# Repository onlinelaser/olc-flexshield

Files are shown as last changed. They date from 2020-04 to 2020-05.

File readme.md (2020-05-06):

## FLEXSHIELD v1

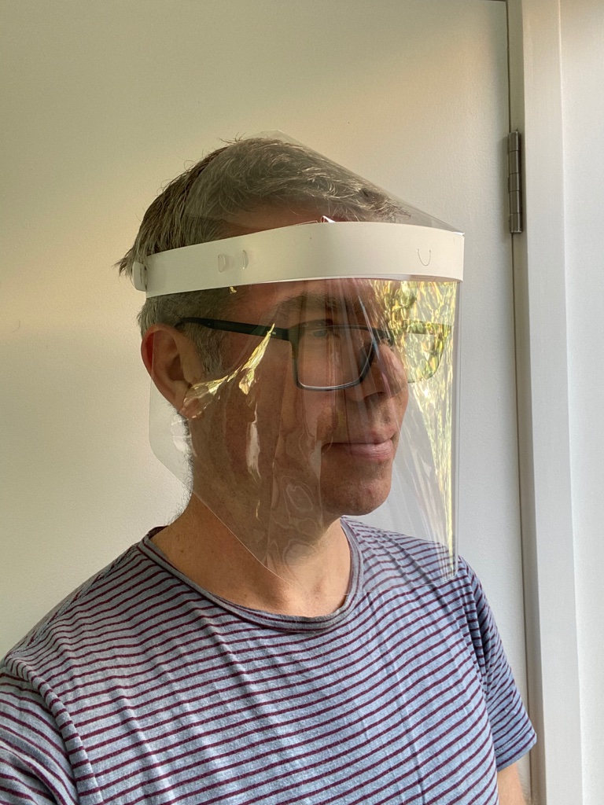
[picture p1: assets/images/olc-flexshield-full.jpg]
Full face variant


This is a disposable and/or reusable face shield design, it's currently in the early stages of review by our local hospitals and this iteration addresses a couple of issues from our previous design.

1) Integrated shield cover now extends coverage over the front of the top of the head.

2) Fully sanitisable materials in Isopropyl alcohol - specifically no foam or adhesive parts are required that would be degraded by washing/sanitising

3) Split the design into a Full Face version that wraps over the top of the head for more protection and a standard version that simply wraps around the face and can be produced in larger quantities.

**Note that this is not an approved medical or protective device and has not been tested or certified as fit for any restricted use.**

## Source attribution
[Online Laser Cutting](https://onlinelasercutting.com.au)

## Open Source License
Copyright Online Laser Cutting Pty Ltd 2020.

This source describes Open Hardware and is licensed under the CERN-OHL-P
v2

You may redistribute and modify this documentation and make products
using it under the terms of the CERN-OHL-P v2 (https:/cern.ch/cern-ohl).

This documentation is distributed WITHOUT ANY EXPRESS OR IMPLIED
WARRANTY, INCLUDING OF MERCHANTABILITY, SATISFACTORY QUALITY
AND FITNESS FOR A PARTICULAR PURPOSE. Please see the CERN-OHL-P v2
for applicable conditions

## Sterilising protocol
Designed to withstand sterilising in 99%+ Alochol based on:
See: https://www.calpaclab.com/polypropylene-chemical-compatibility-chart/  
See: https://www.usplastic.com/knowledgebase/article.aspx?contentkey=569

Initial testing on a 50 deg Centigrade VHP cycle indicated shield was still 
fully functional after 5 cycles - more testing is required however.

## Lifespan:
Single or Multiple use.  
Should happily withstand multiple 99% Alcohol wash cycles and appears fine with low temperature VHP sterilisation.

## Design notes:
Strap size should fit 97%+ of the population

## BOM
* 1 x 0.1mm Polyester OR 0.5mm PETG faceplate
* 1 x 0.8mm Polypropylene head band
* 1 x 0.8mm Polypropylene brow strap

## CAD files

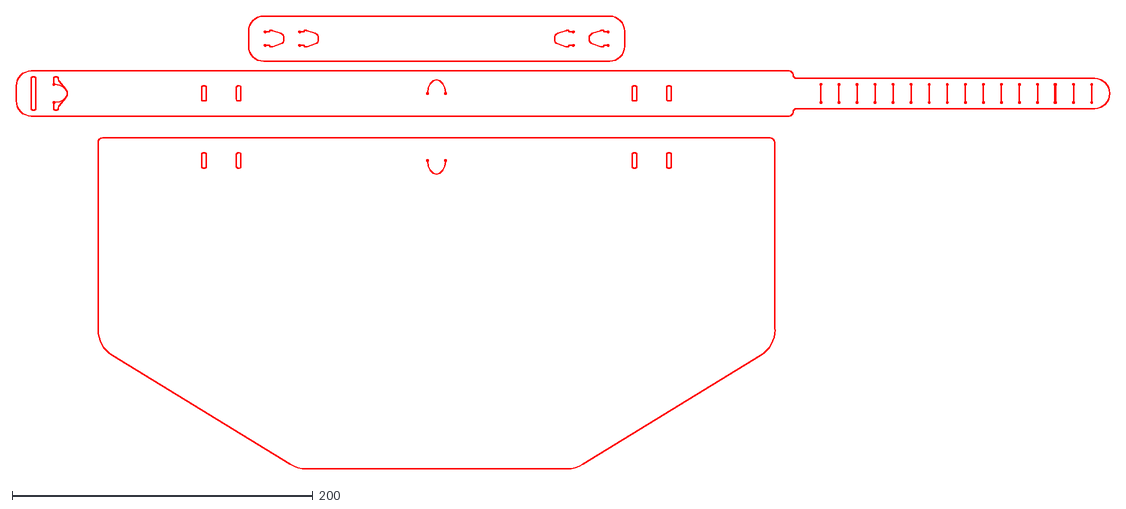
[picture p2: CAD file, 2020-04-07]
Flexible Frame Standard.dxf
726.9 x 301.0

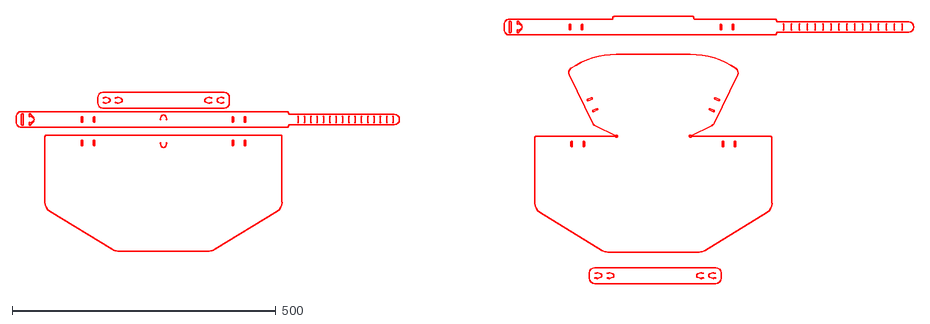
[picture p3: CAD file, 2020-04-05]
Flexible Frame.dxf
1702.5 x 506.5

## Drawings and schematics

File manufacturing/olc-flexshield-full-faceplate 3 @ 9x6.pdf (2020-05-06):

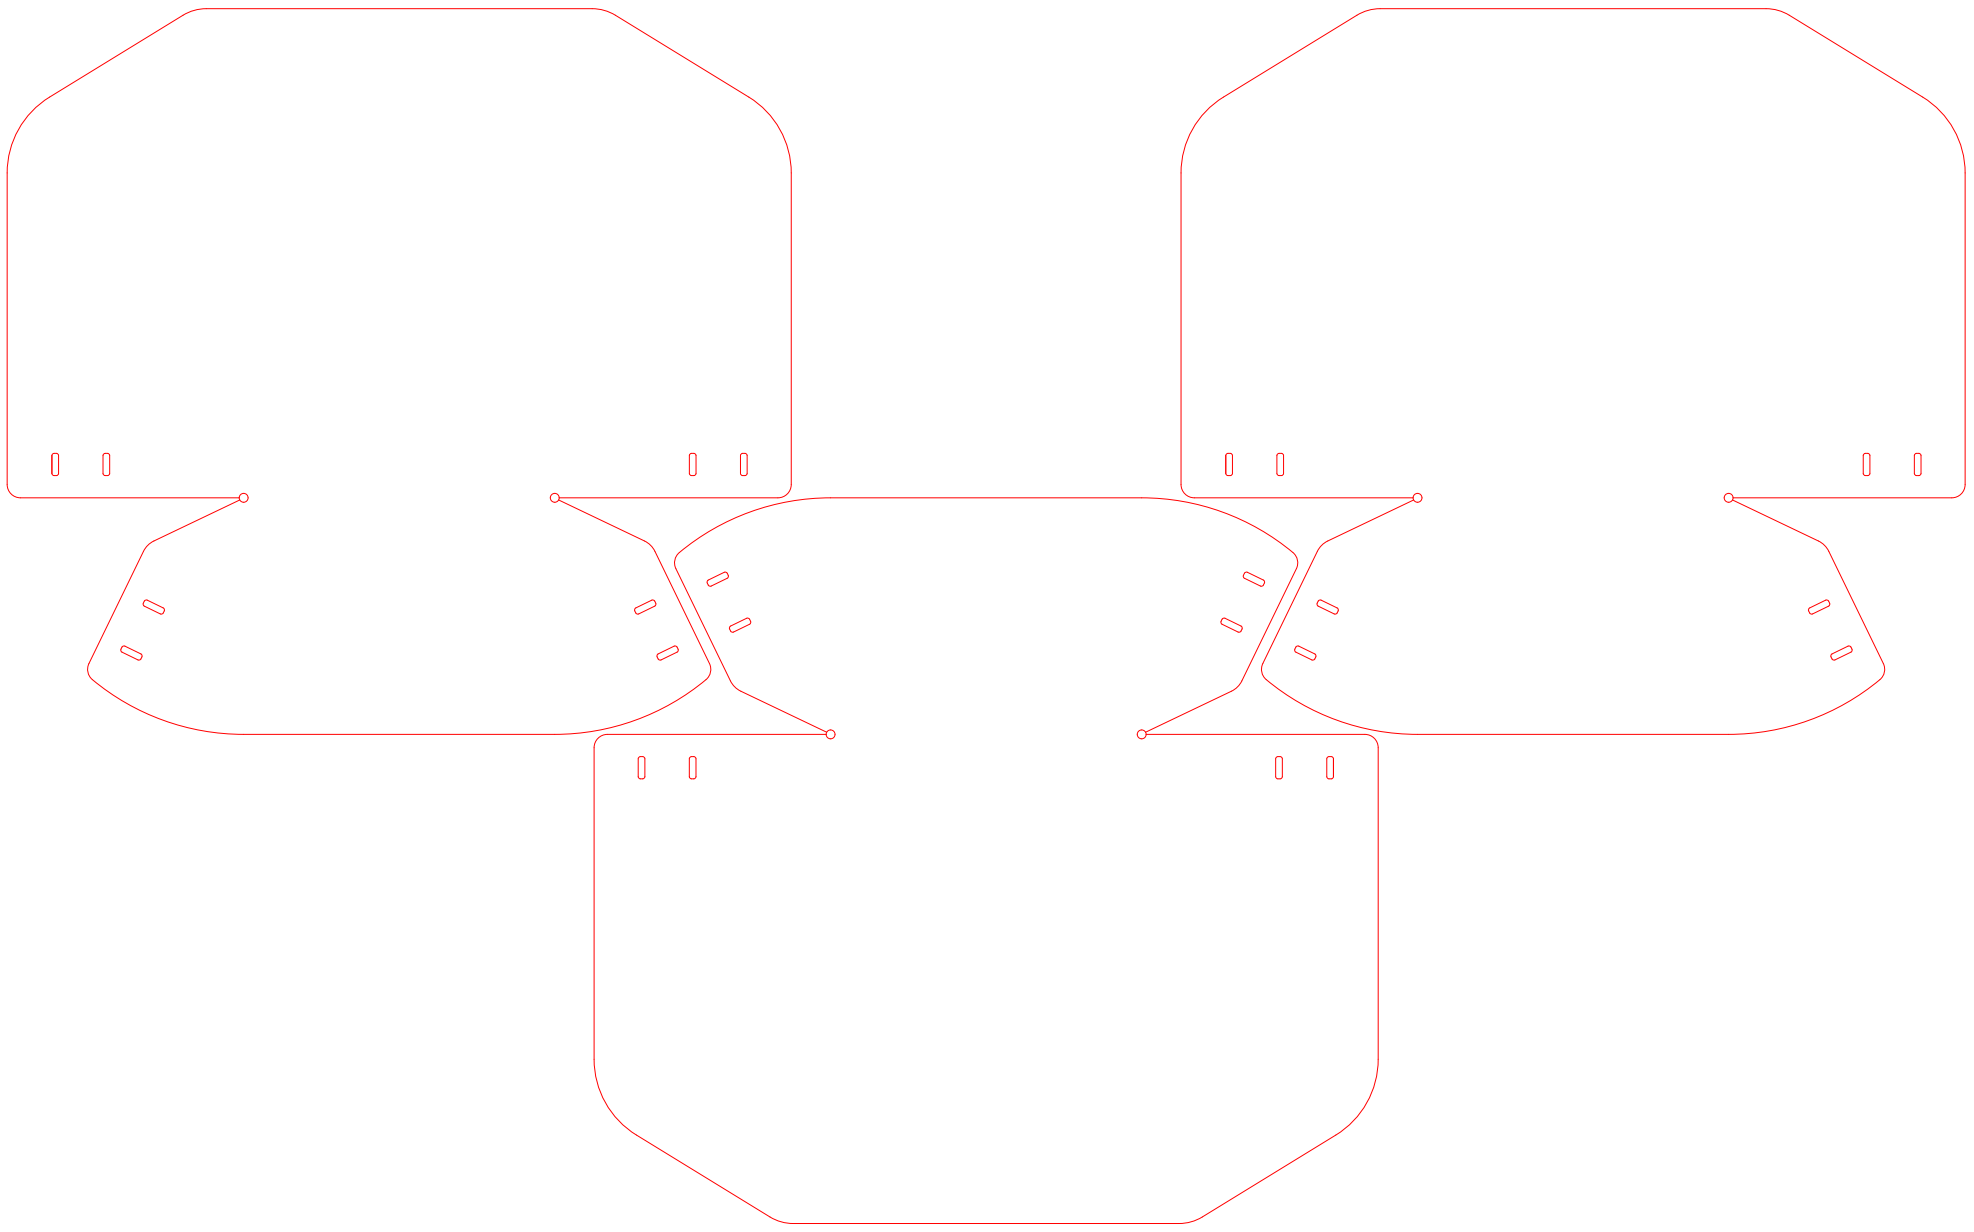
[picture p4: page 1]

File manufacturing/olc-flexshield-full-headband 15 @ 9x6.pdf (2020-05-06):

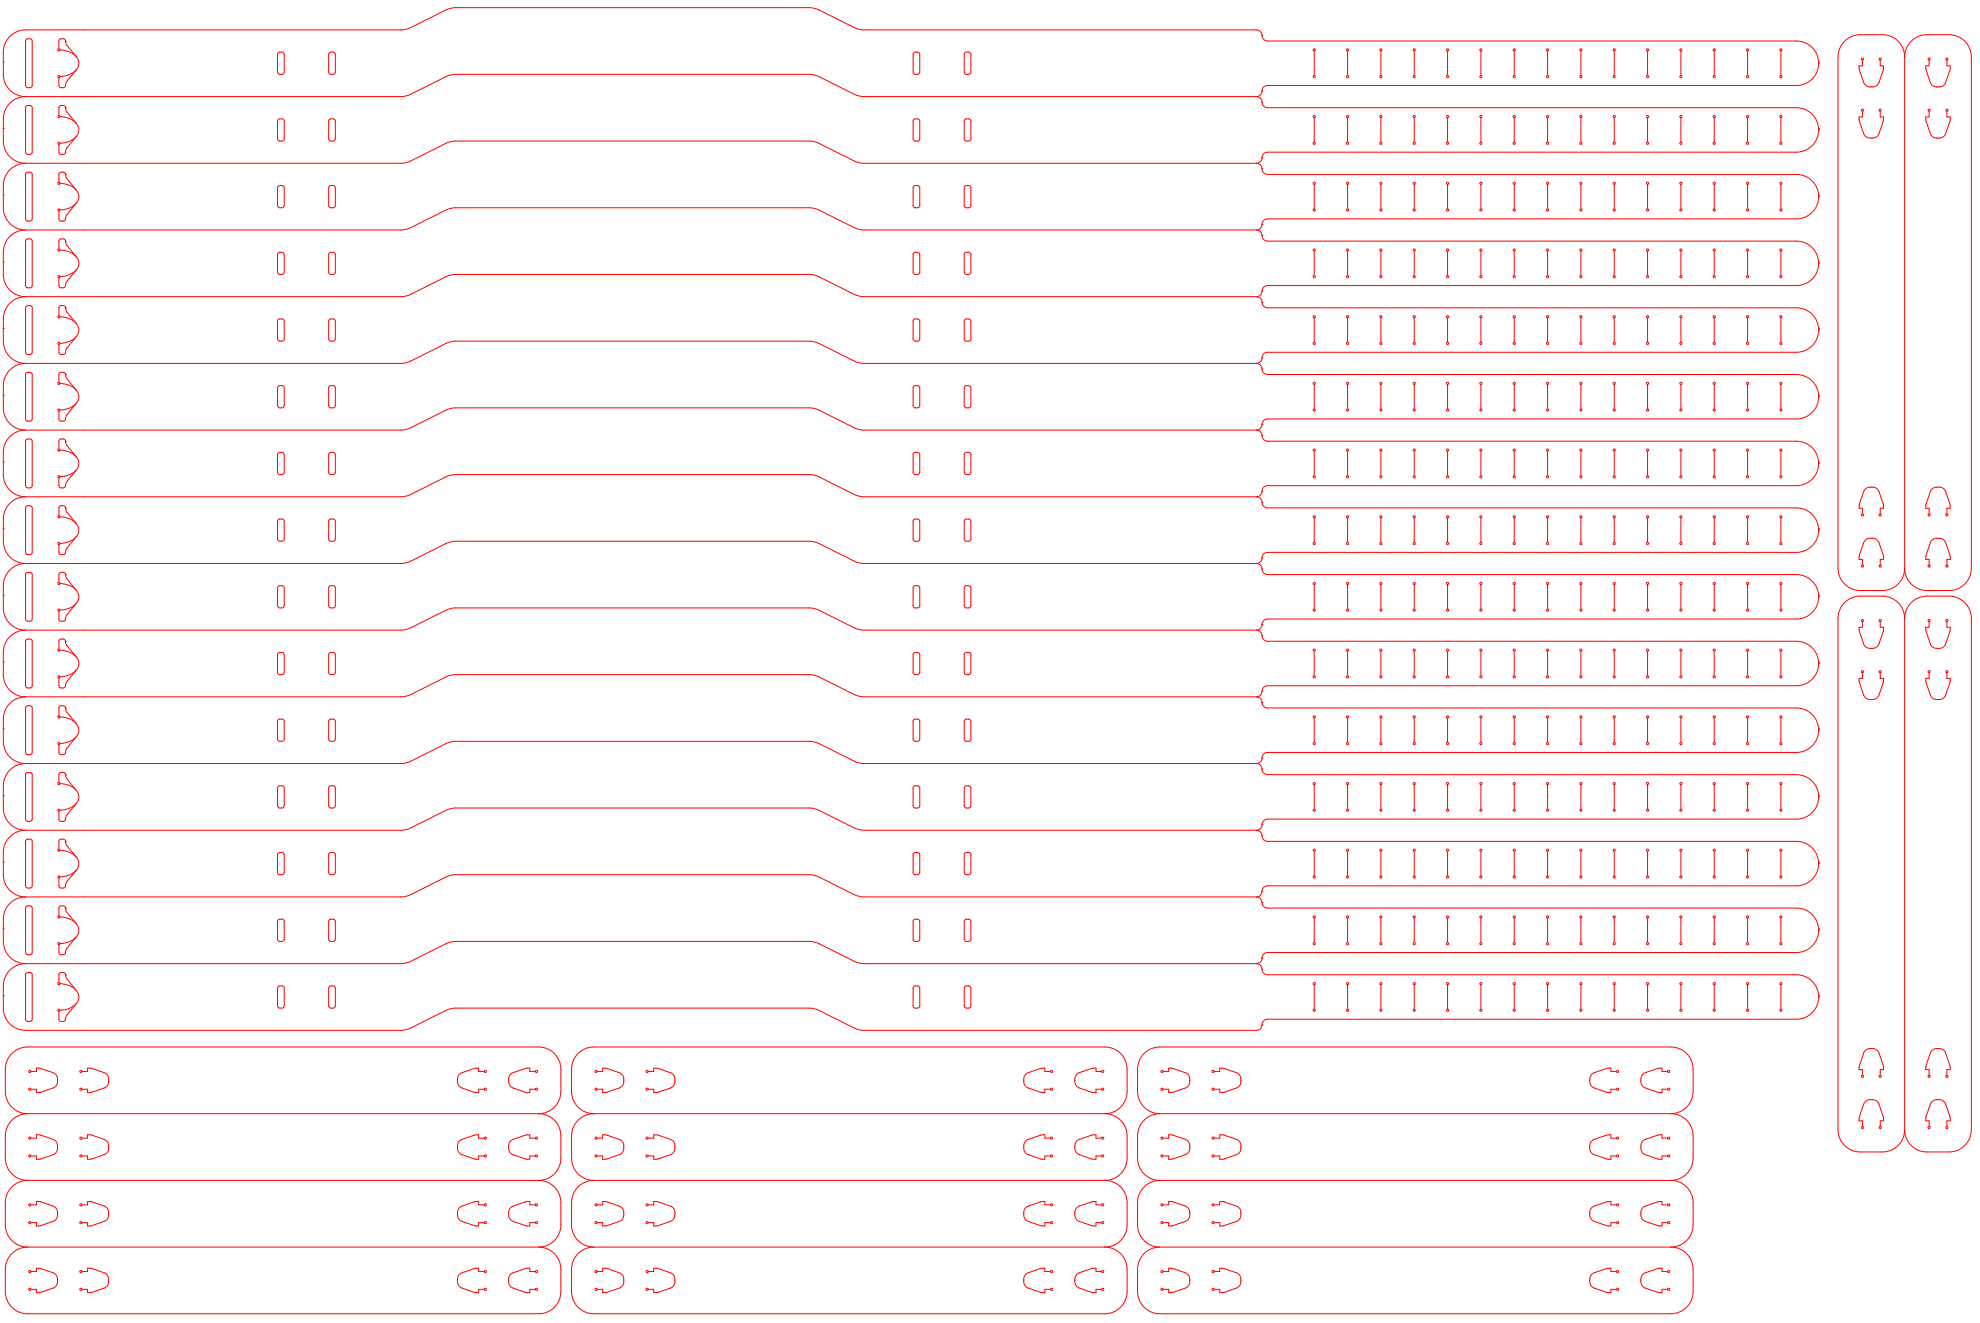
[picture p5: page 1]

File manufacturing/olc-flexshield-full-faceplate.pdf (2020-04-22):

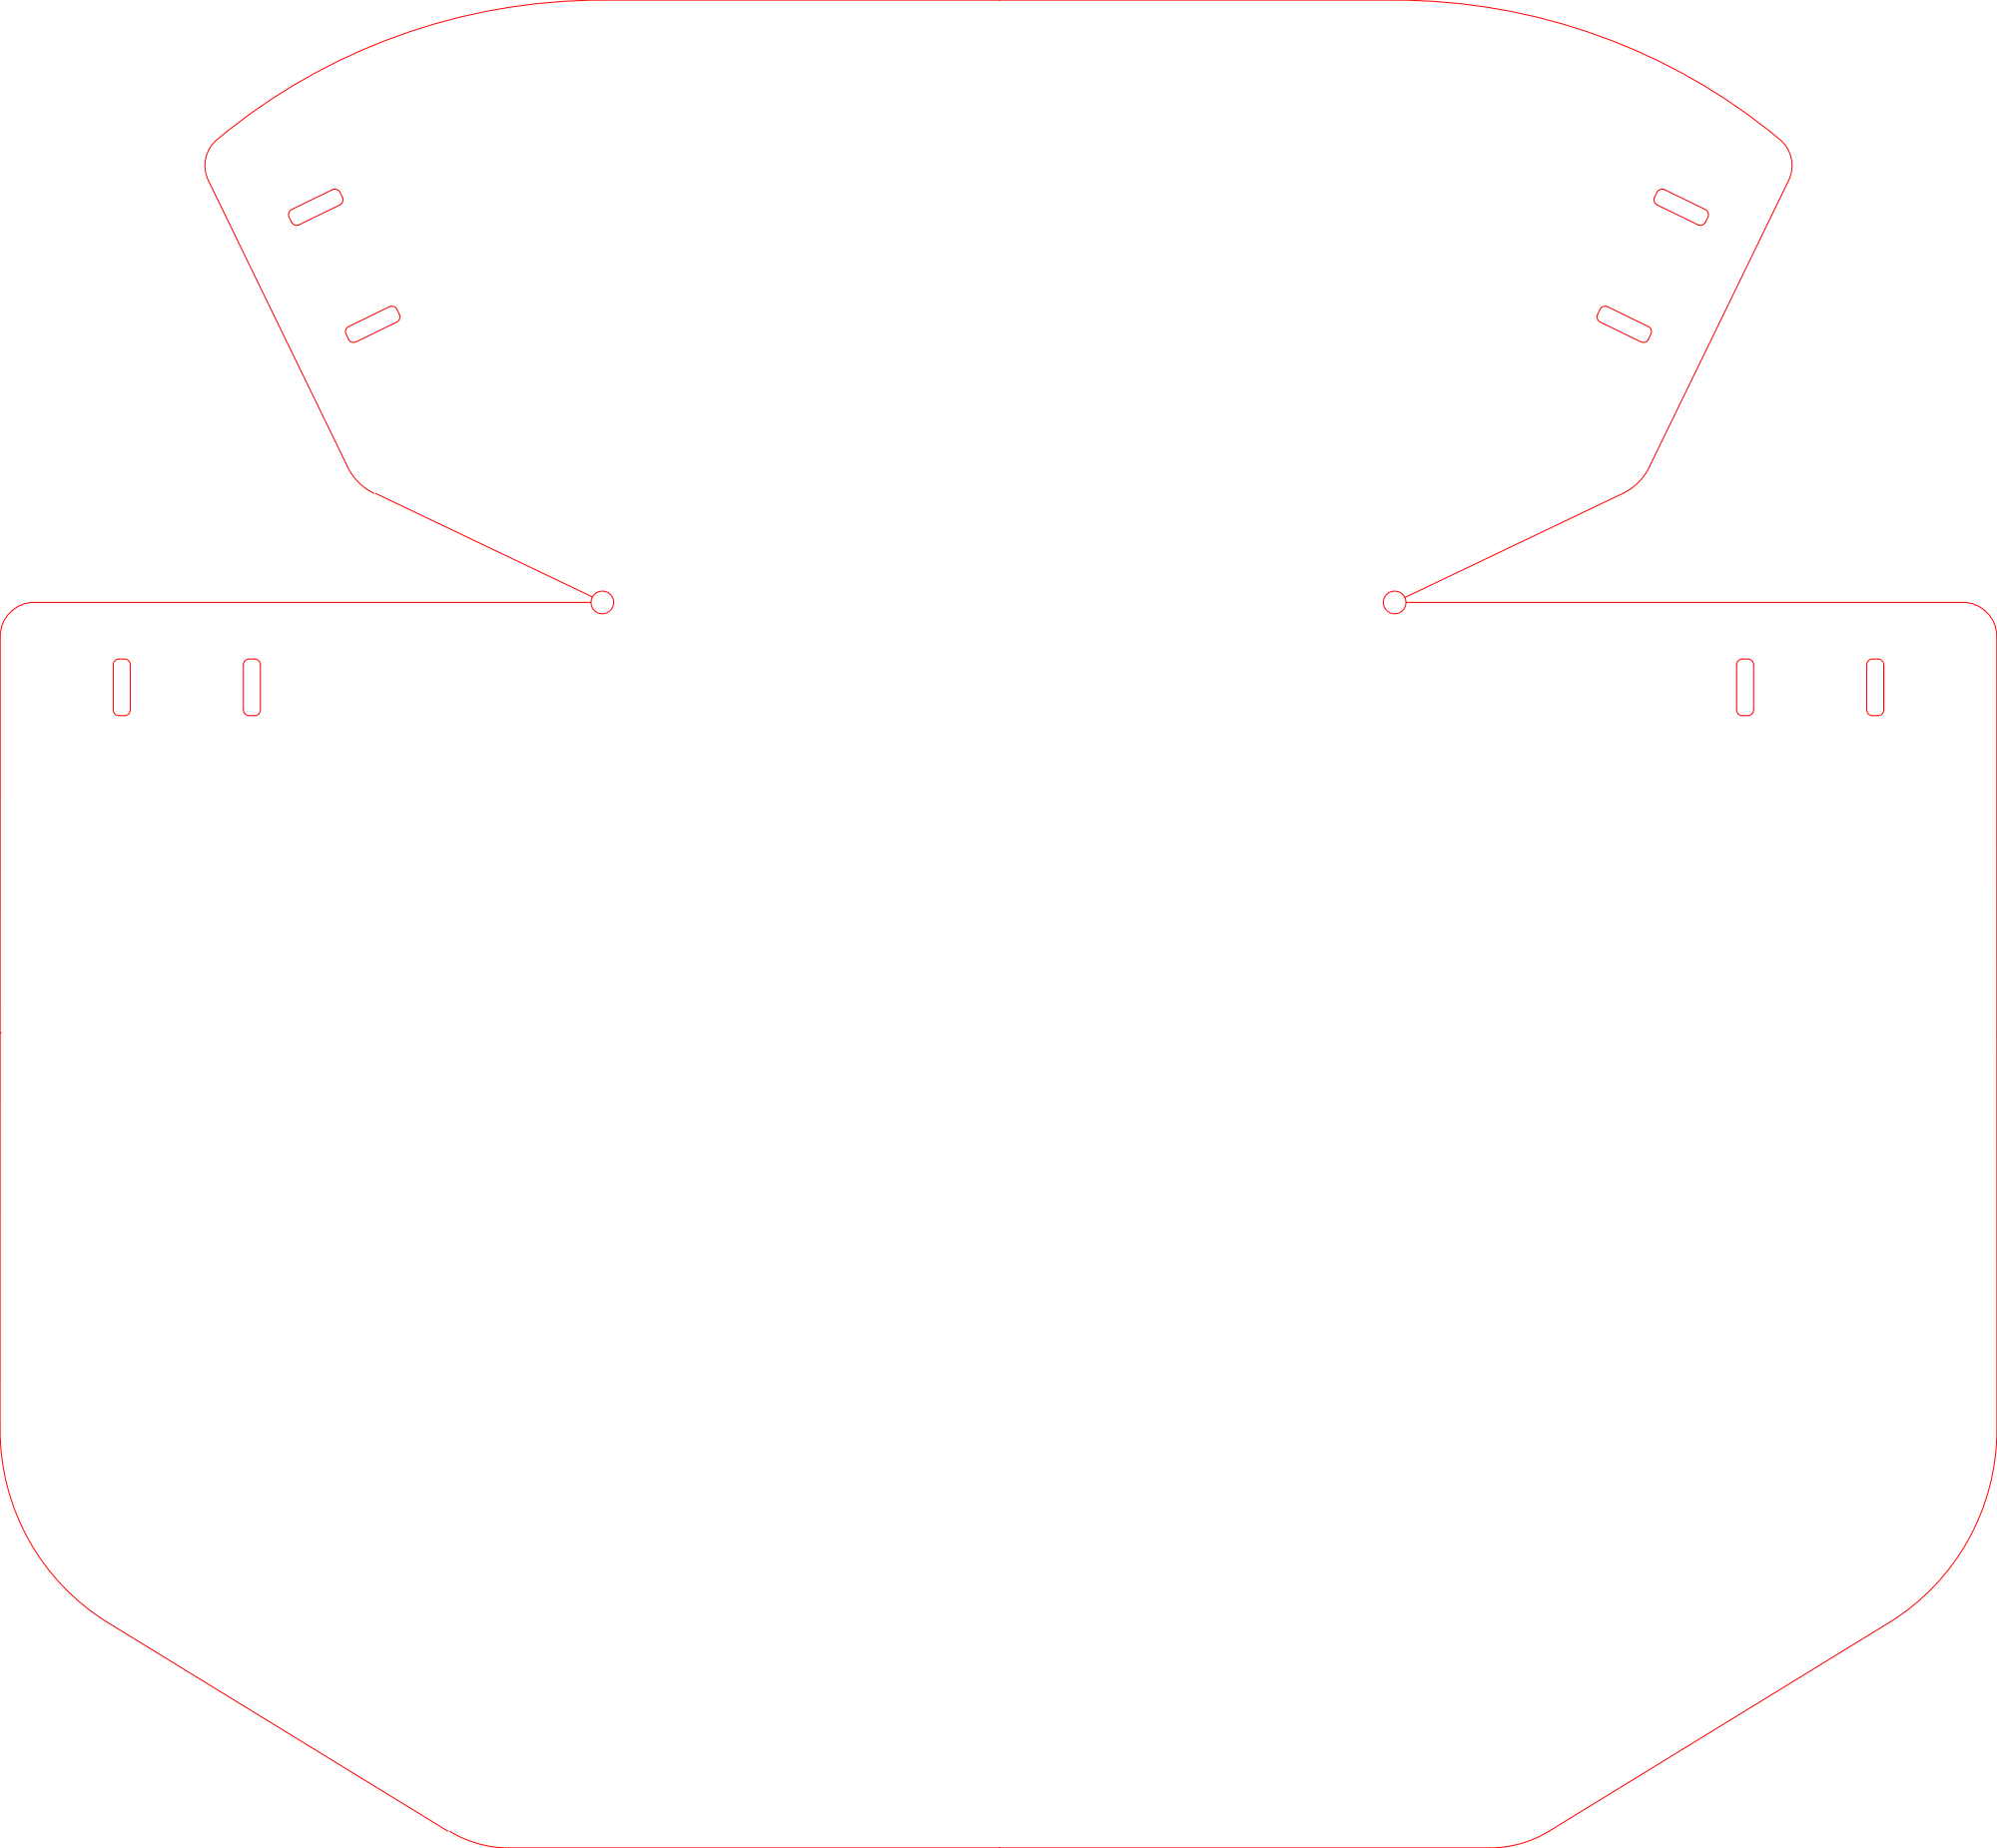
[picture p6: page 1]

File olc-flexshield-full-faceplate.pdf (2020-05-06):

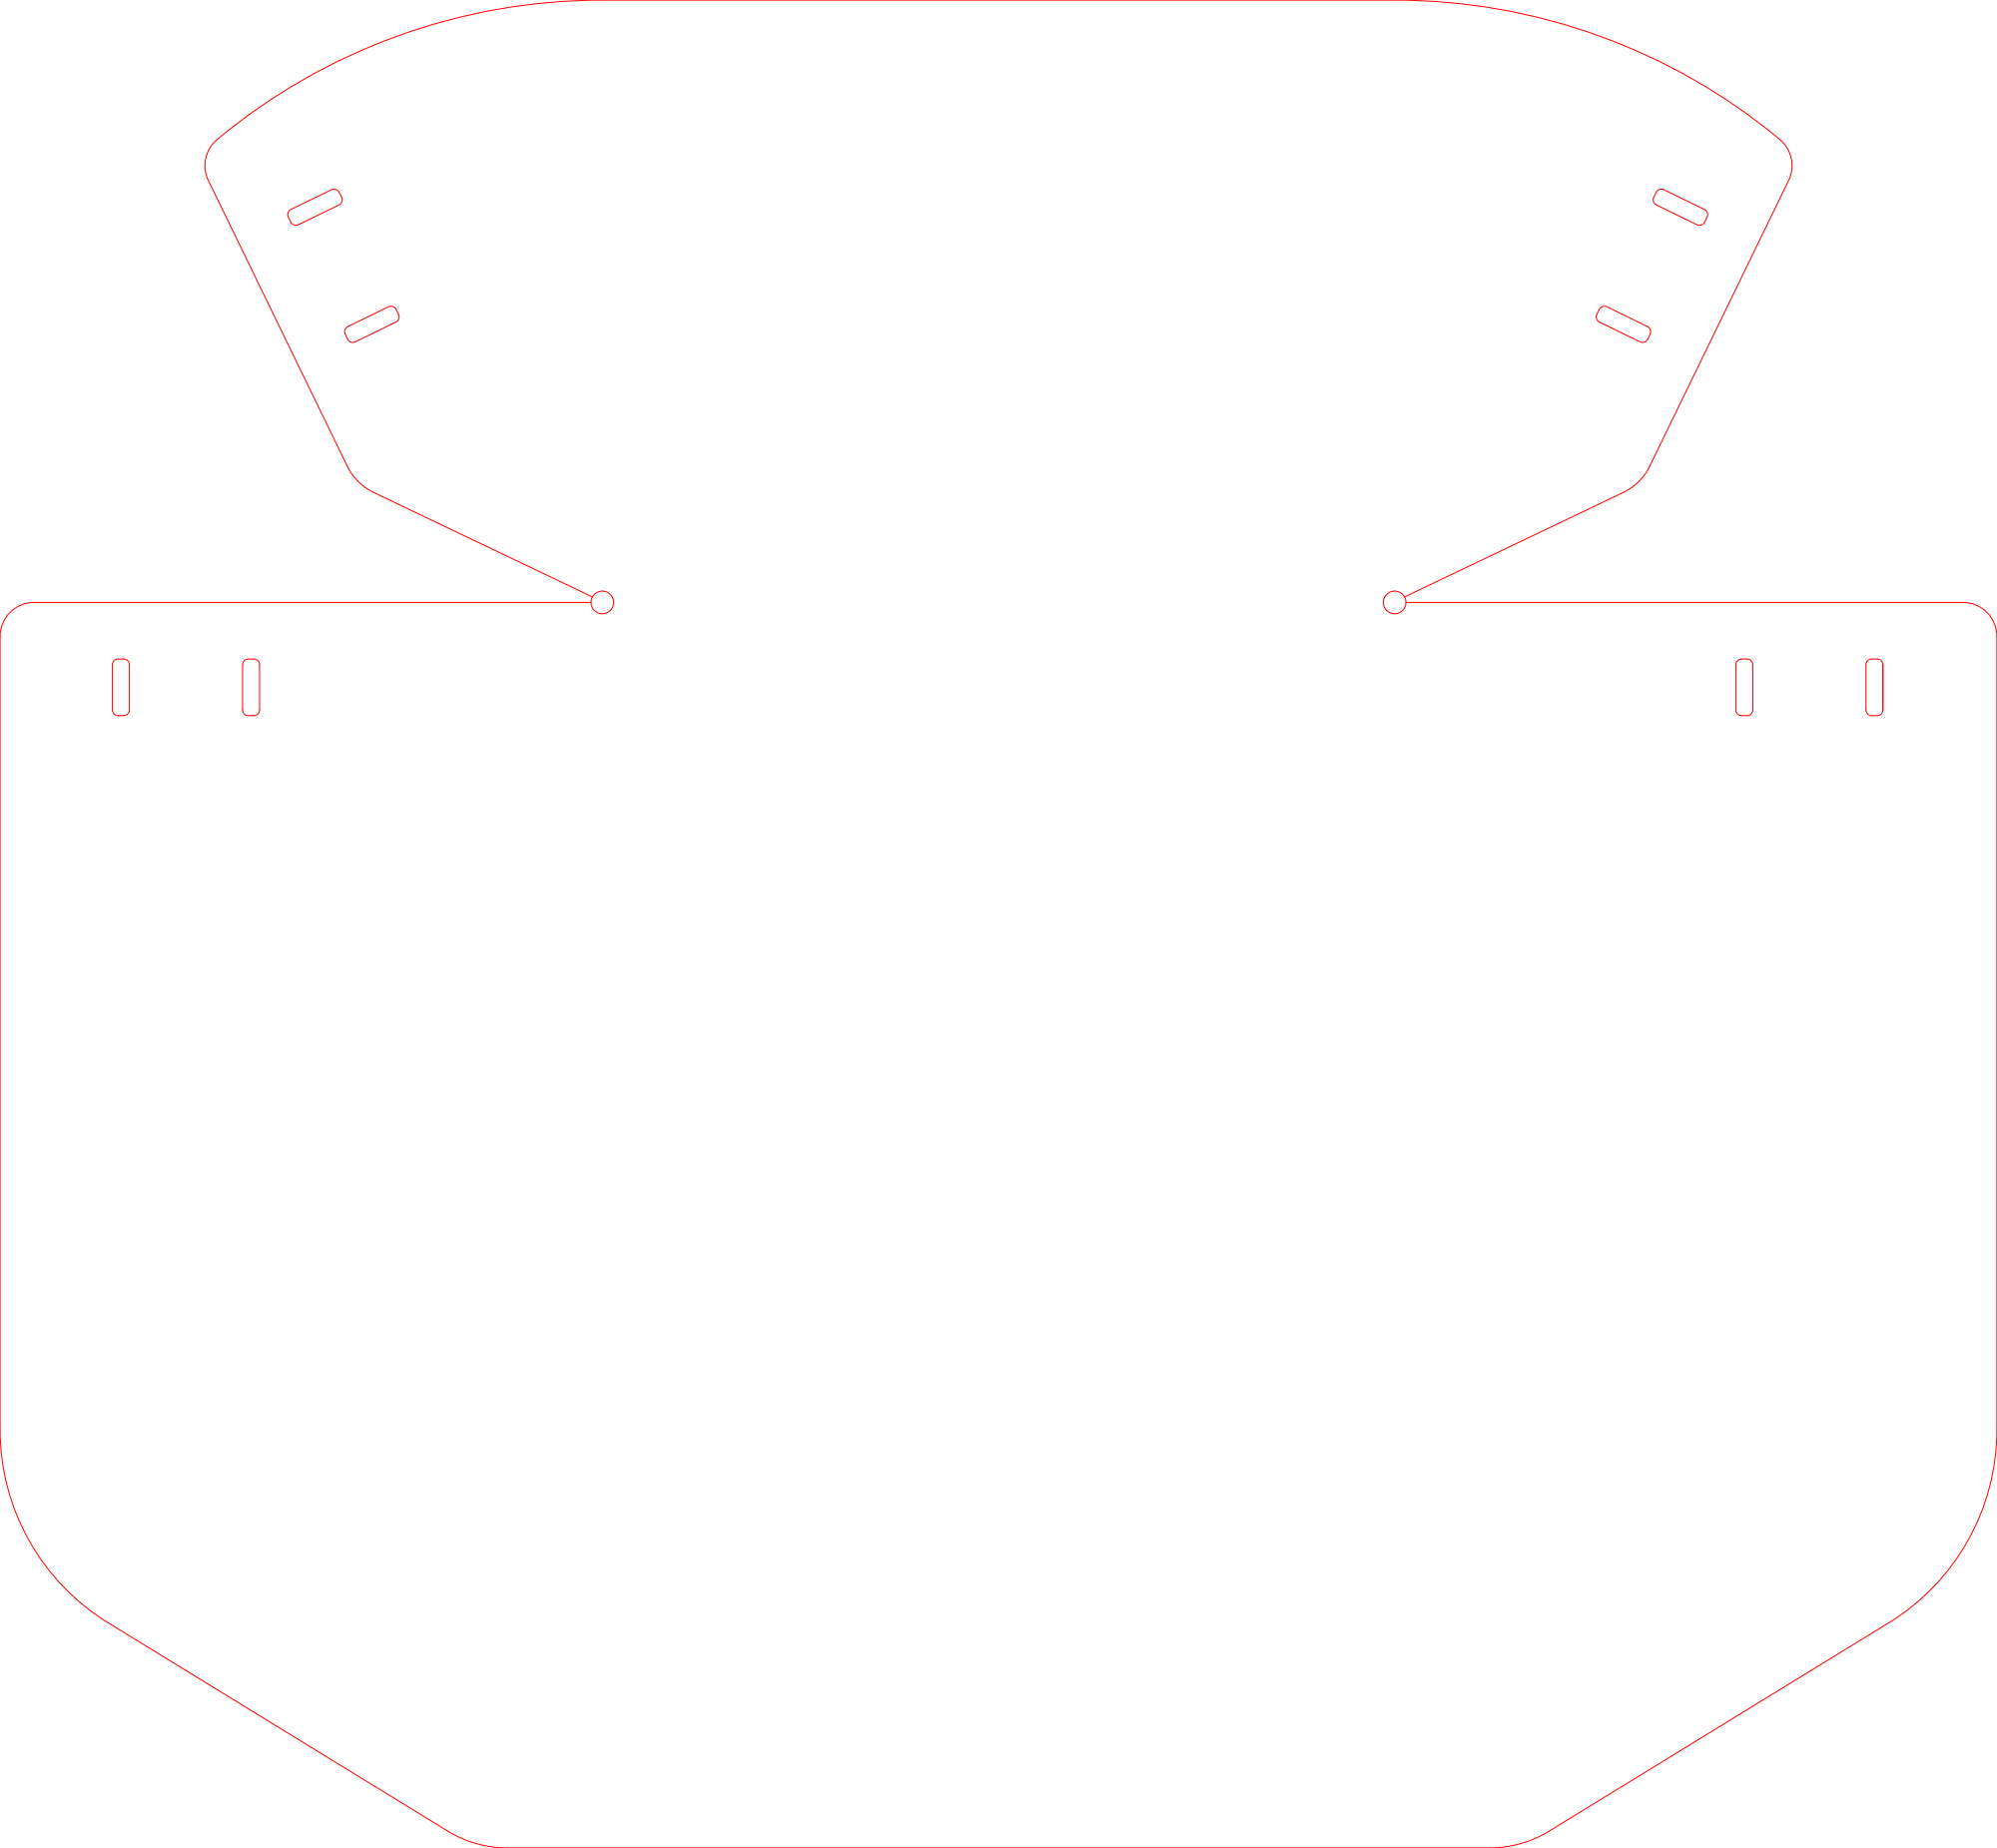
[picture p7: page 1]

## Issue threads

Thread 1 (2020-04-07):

Add assembly instructions

onlinelaser, 2020-04-07:
There are a couple of things that can go wrong during assembly that reduce the efficacy of the shield, the assembly procedure needs to be added or these need to be designed out in the next revision.

Correct assembly is something like:

1) Place the clear faceplate piece on a table with the ‘chin’ of the faceplate nearest to you
Take the small white headband, the two white tabs on the left of the headband through the lower pair of slots on the left of the faceplate

2) Now curl the faceplate until you can push the right side white tabs through the right side slots on the faceplate

3) Fold the top of the faceplate over until the top slots align with the tabs and you can push the headband tabs through them.

4) Now take the large white headband, it clips through the tabs in the same way, the top of the headband is the slightly raised section - make sure that is oriented to the top to cover the fold holes in the mylar.

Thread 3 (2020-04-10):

Allow for larger heads

onlinelaser, 2020-04-10:
Add more notches and extend length of strap, remove a couple from the shorter end as it doesn’t need to go that small

Closed 2020-04-10.

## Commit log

2020-04-07 Split into two files for the small and large variants
    [Flexible Frame Full Face.dxf, Flexible Frame Standard.dxf]
2020-04-07 Increased height of crest to improve coverage of holes
    [Flexible Frame Full Face.dxf]
2020-04-10 Update Flexible Frame Full Face.dxf
    Made headband wider, should adjust for head circumference from about 48 to 69cm now
    [Flexible Frame Full Face.dxf]
2020-04-10 Make the face plate narrower
    Closes #2 by making the face shield approx 60mm narrower to 390mm wide.
    [Flexible Frame Full Face.dxf]
2020-04-12 Indent under the crest
    Improves nesting on the sheet, closes #4
    [Flexible Frame Full Face.dxf]
2020-04-18 Shorten shield again, closes #2
    [Flexible Frame Full Face.dxf]
2020-04-27 Increase grab on tabs, straighten faceplate edges
    Closes #5
    [Flexible Frame Full Face.dxf]
2020-05-06 Revert tab sizes
    [Flexible Frame Full Face.dxf]
